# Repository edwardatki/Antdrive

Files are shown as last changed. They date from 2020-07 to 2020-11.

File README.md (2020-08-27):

# Antdrive
A lightweight motor driver designed for antweight combat robots. Setup instructions are available [here](https://github.com/edwardatki/Antdrive/blob/master/documentation/guide.pdf).

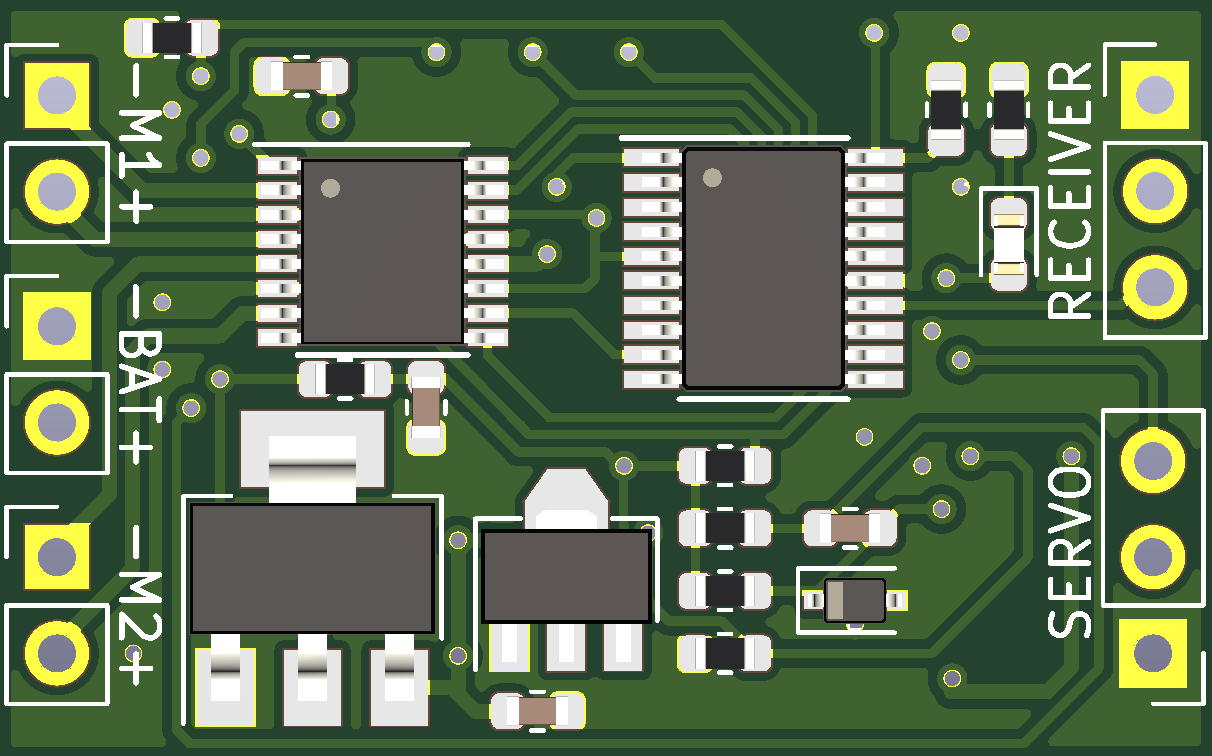
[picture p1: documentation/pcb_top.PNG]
PCB Top

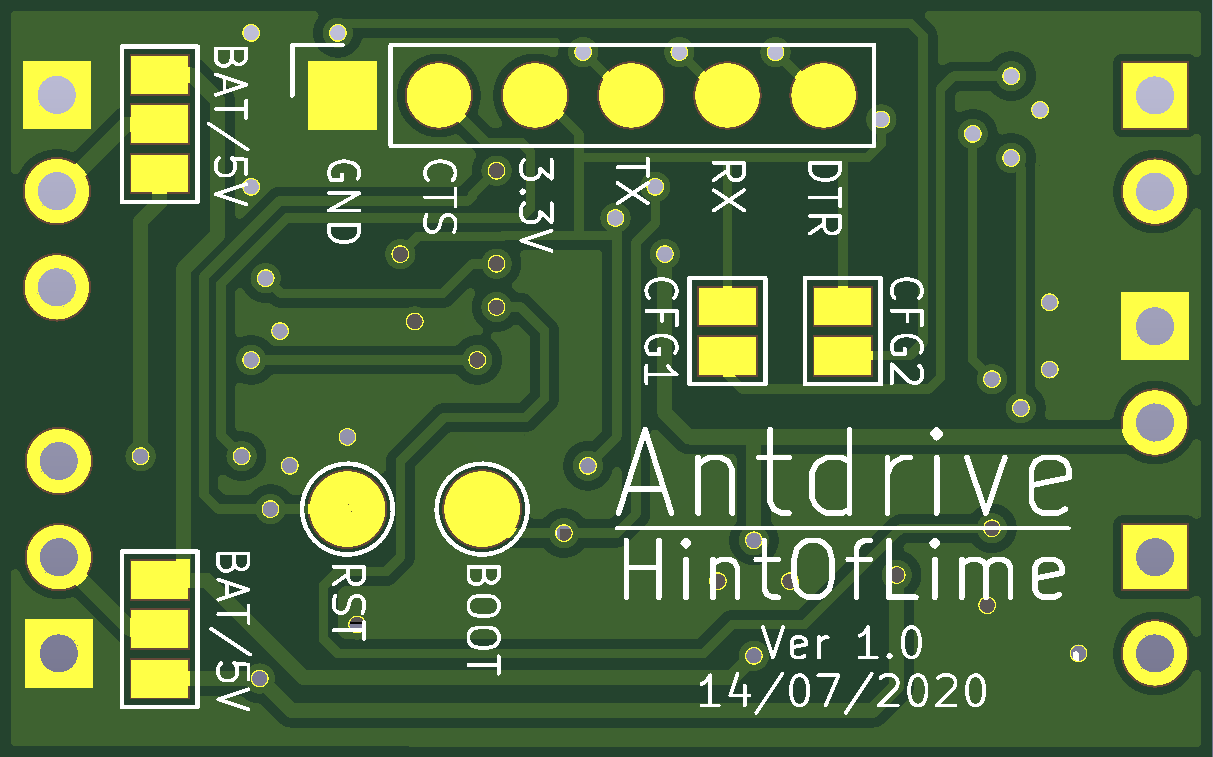
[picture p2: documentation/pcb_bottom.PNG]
PCB Bottom


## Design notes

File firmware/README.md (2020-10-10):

# Programming guide
#### Required software
You will need to have the following software installed
* [Arduino IDE](https://www.arduino.cc/en/Main/software)
* [STM32CubeProgrammer](https://www.st.com/en/development-tools/stm32cubeprog.html)

#### Install STM32 cores
1. In the Arduino IDE goto 'File' and then 'Preferences'
2. Add the following link to the 'Additional Boards Manager URLs' field:
https://github.com/stm32duino/BoardManagerFiles/raw/master/STM32/package_stm_index.json
3. Click 'Ok' to close the menu
4. Goto 'Tools', then 'Boards' and then click on 'Boards Manager'
5. Select 'STM32' Cores and click 'Install'
6. STM32 boards should now show up in the board selection menu

#### Board settings
In the tools menu make sure your board settings match this image
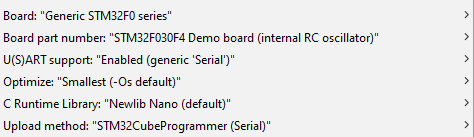
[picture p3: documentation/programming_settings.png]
Board settings


#### Programming
1. Connect and FTDI and select the appropriate COM port
2. Press the FTDI to the corresponding set of pads on the board
3. Press upload
4. Keep pressing the FTDI to the board until the upload it complete

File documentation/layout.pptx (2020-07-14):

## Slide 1

Status LED

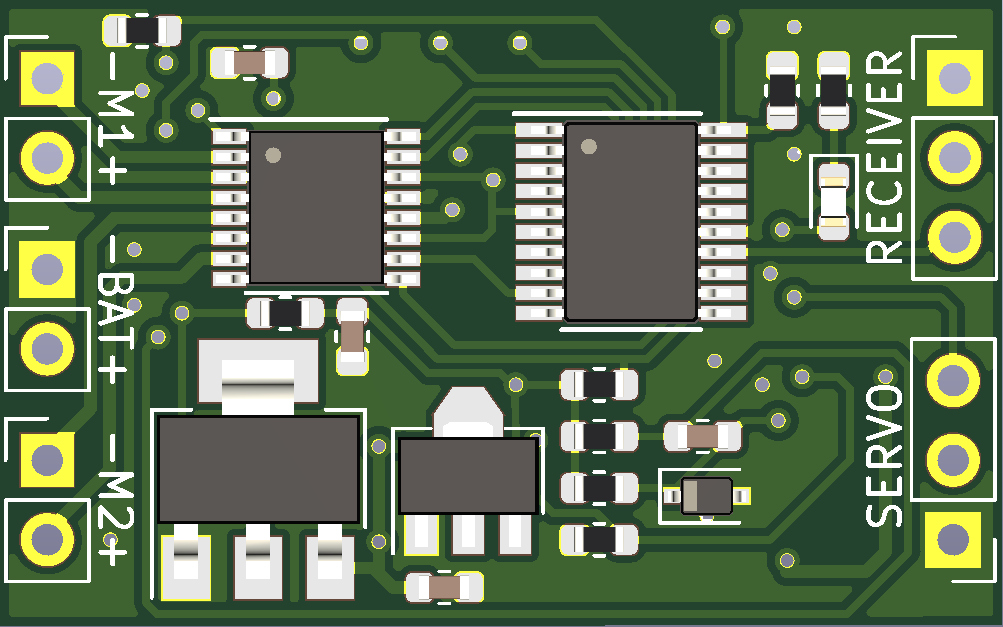
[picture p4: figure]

Motor 1

Receiver

Battery

Motor 2

Servo or ESC

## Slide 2

Programming pads

Configuration jumpers

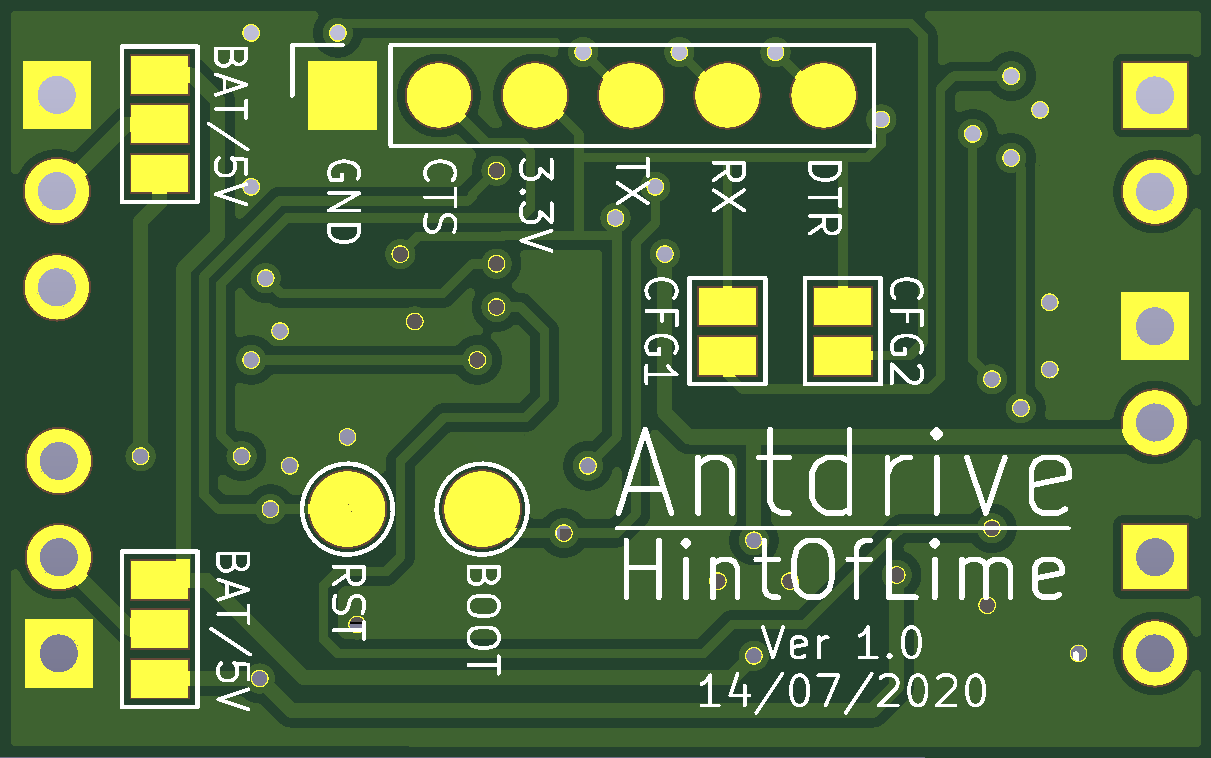
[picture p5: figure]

Voltage selection jumpers

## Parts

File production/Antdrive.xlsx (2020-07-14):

Comment | Designator | Footprint | LCSC Part
AMS117-5.0 | U1 | SOT-223-3 | C6187
STM32F030F4P6TR | U2 | TSSOP-20 | C89040
DRV8848PWPR | U3 | TSSOP-16 | C131079
HT7533-1 | U5 | SOT-89-3 | C14289
1kΩ | R1, R2, R3, R6, R8 | 0603 | C21190
220Ω | R4 | 0603 | C22962
100kΩ | R5 | 0603 | C25803
10kΩ | R7 | 0603 | C25804
10uF | C1, C2, C3 | 0603 | C19702
2.2uF | C4 | 0603 | C23630
KT-0603R | D1 | 0603 | C2286
KDZ3.3V-RTK/P | D2 | SOD-323 | C155470

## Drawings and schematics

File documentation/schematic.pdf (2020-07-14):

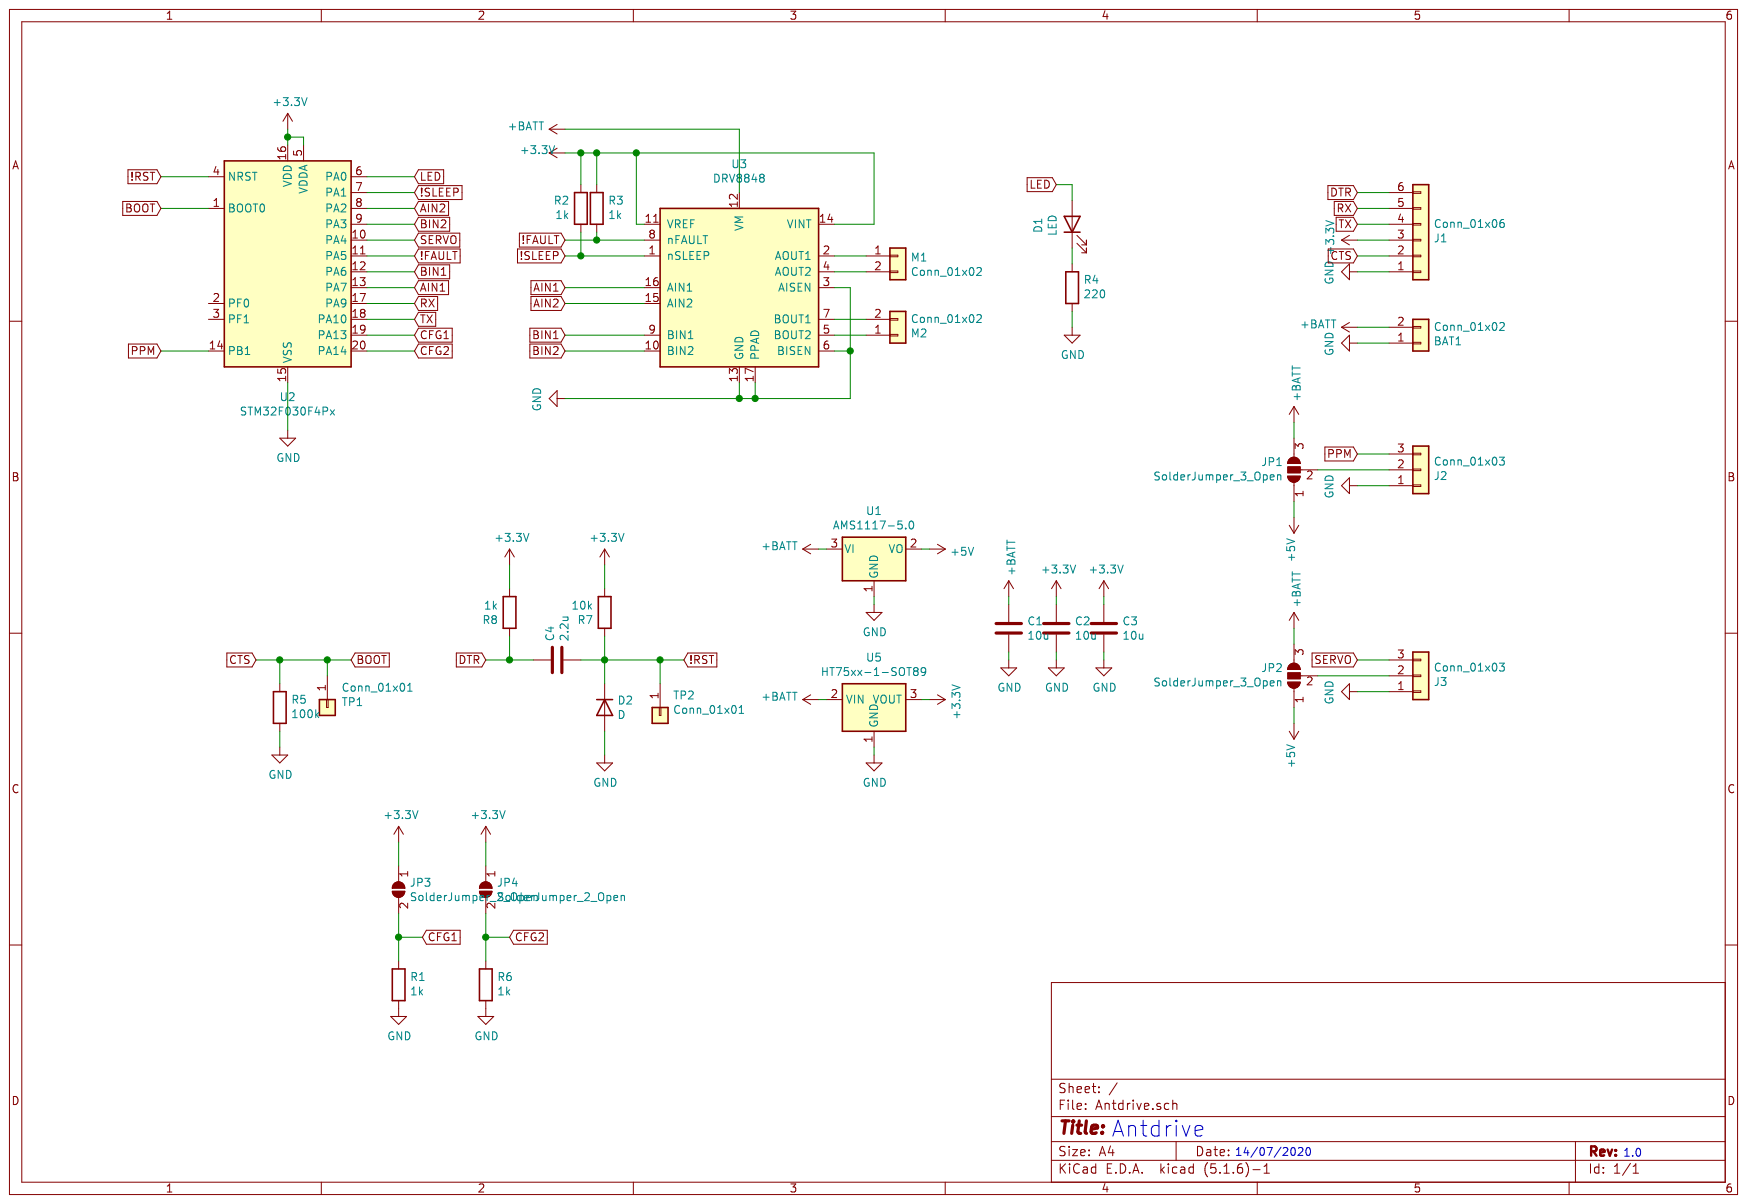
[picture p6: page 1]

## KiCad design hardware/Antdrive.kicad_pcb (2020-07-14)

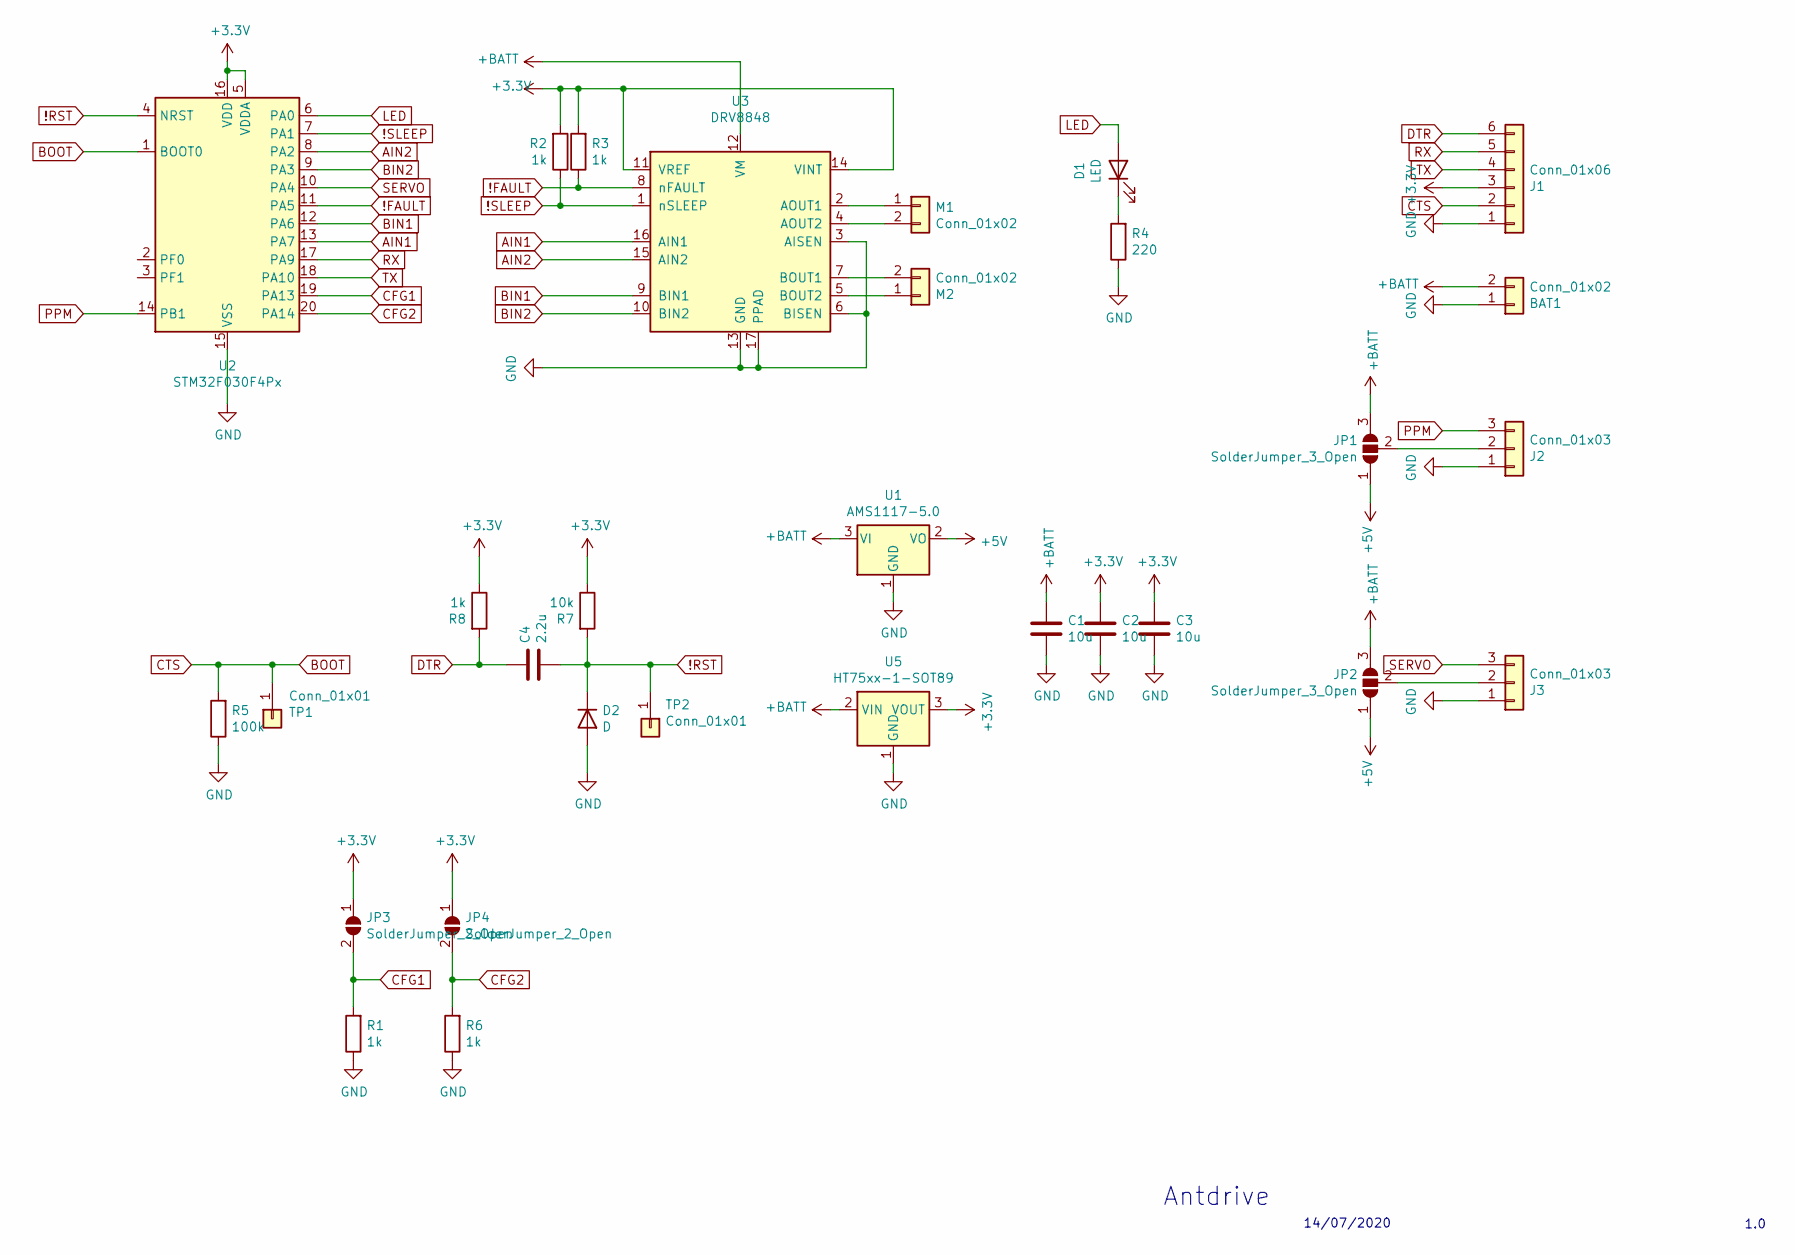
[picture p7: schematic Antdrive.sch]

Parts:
BAT1: Conn_01x02; PinHeader_1x02_P2.54mm_Vertical
C1, C2, C3: 10u; C_0603_1608Metric
C4: 2.2u; C_0603_1608Metric
D1: LED; LED_0603_1608Metric
D2: D; D_SOD-323
J1: Conn_01x06; PinSocket_1x06_P2.54mm_Vertical
J2, J3: Conn_01x03; PinHeader_1x03_P2.54mm_Vertical
JP1, JP2: SolderJumper_3_Open; SolderJumper-3_P1.3mm_Open_Pad1.0x1.5mm_NumberLabels
JP3, JP4: SolderJumper_2_Open; SolderJumper-2_P1.3mm_Open_Pad1.0x1.5mm
M1, M2: Conn_01x02; PinHeader_1x02_P2.54mm_Vertical
R1, R2, R3, R6, R8: 1k; R_0603_1608Metric
R4: 220; R_0603_1608Metric
R5: 100k; R_0603_1608Metric
R7: 10k; R_0603_1608Metric
TP1, TP2: Conn_01x01; TestPoint_Pad_D2.0mm
U1: AMS1117-5.0; SOT-223-3_TabPin2
U2: STM32F030F4Px; TSSOP-20_4.4x6.5mm_P0.65mm
U3: DRV8848; TSSOP-16-1EP_4.4x5mm_P0.65mm
U5: HT75xx-1-SOT89; SOT-89-3

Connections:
!FAULT: R3.1, U2.11 (PA5), U3.8 (nFAULT)
!RST: C4.2, D2.1 (K), R7.2, TP2.1, U2.4 (NRST)
!SLEEP: R2.1, U2.7 (PA1), U3.1 (nSLEEP)
+3V3: C2.1, C3.1, J1.3, JP3.1 (A), JP4.1 (A), R2.2, R3.2, R7.1, R8.1, U2.5 (VDDA), U2.16 (VDD), U3.11 (VREF), U3.14 (VINT), U5.3 (VOUT)
+5V: JP1.1 (A), JP2.1 (A), U1.2 (VO)
+BATT: BAT1.2, C1.1, JP1.3 (B), JP2.3 (B), U1.3 (VI), U3.12 (VM), U5.2 (VIN)
AIN1: U2.13 (PA7), U3.16 (AIN1)
AIN2: U2.8 (PA2), U3.15 (AIN2)
BIN1: U2.12 (PA6), U3.9 (BIN1)
BIN2: U2.9 (PA3), U3.10 (BIN2)
BOOT: J1.2, R5.2, TP1.1, U2.1 (BOOT0)
CFG1: JP3.2 (B), R1.2, U2.19 (PA13)
CFG2: JP4.2 (B), R6.2, U2.20 (PA14)
DTR: C4.1, J1.6, R8.2
GND: BAT1.1, C1.2, C2.2, C3.2, D2.2 (A), J1.1, J2.1, J3.1, R1.1, R4.1, R5.1, R6.1, U1.1 (GND), U2.15 (VSS), U3.3 (AISEN), U3.6 (BISEN), U3.13 (GND), U3.17 (PPAD), U5.1 (GND)
LED: D1.2 (A), U2.6 (PA0)
unnamed: D1.1 (K), R4.2
unnamed: J2.2, JP1.2 (C)
unnamed: J3.2, JP2.2 (C)
unnamed: M1.1, U3.2 (AOUT1)
unnamed: M1.2, U3.4 (AOUT2)
unnamed: M2.1, U3.5 (BOUT2)
unnamed: M2.2, U3.7 (BOUT1)
PPM: J2.3, U2.14 (PB1)
RX: J1.5, U2.17 (PA9)
SERVO: J3.3, U2.10 (PA4)
TX: J1.4, U2.18 (PA10)

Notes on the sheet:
14/07/2020
Antdrive
1.0

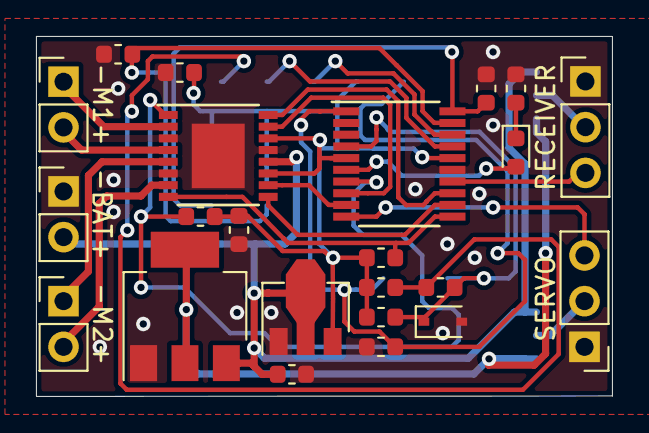
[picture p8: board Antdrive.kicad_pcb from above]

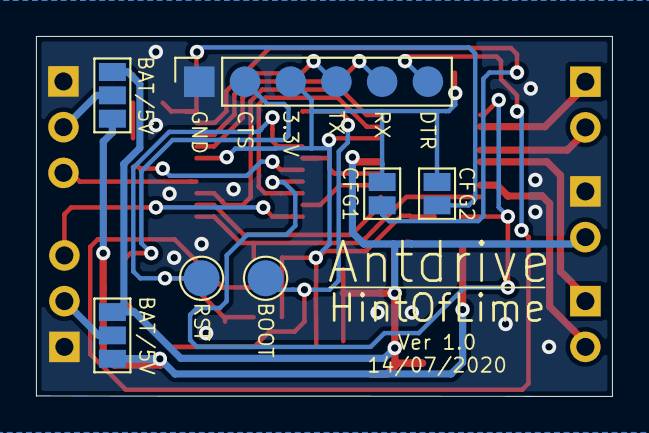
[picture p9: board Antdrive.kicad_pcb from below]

Board: 2 copper layers, 32.0 x 20.0 mm, 30 parts (7 on the bottom side), 27 nets.

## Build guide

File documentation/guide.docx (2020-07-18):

Antdrive V1.0

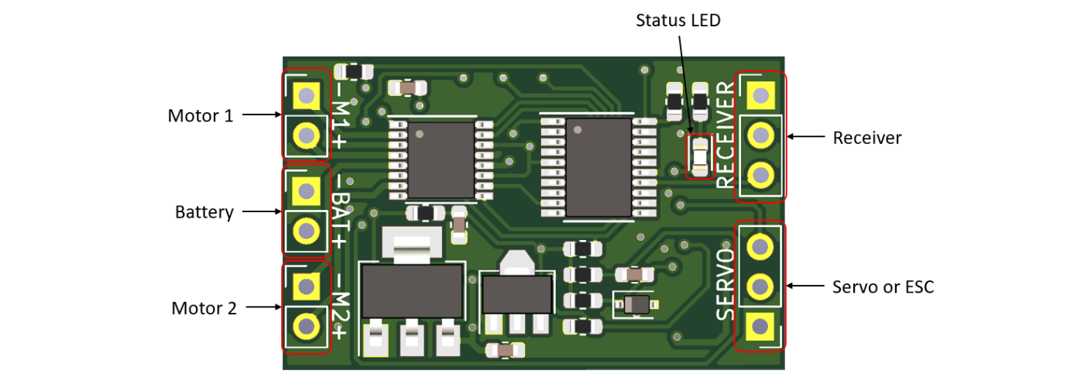
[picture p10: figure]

GND

VCC

SIGNAL

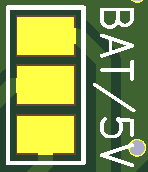
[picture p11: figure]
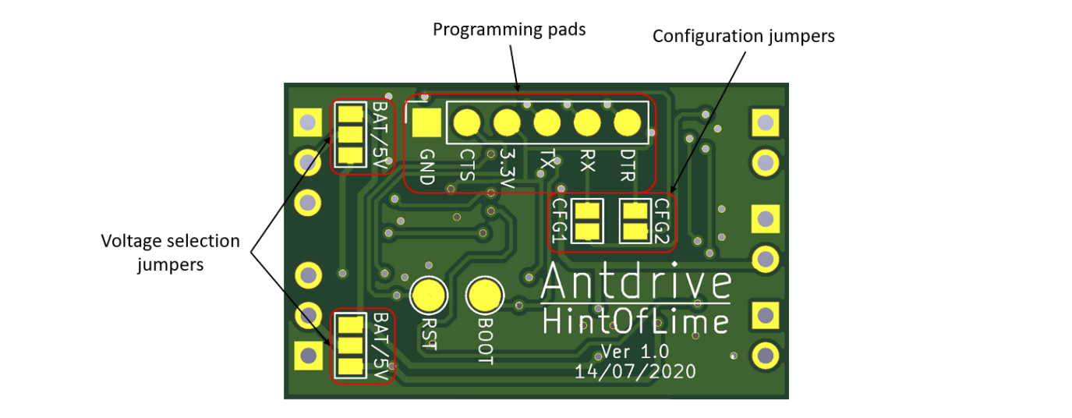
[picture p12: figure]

CFG1 selects the board’s input mode. By default the board will use PPM mode, if jumpered it will use PWM mode.

CFG2 controls whether to mix the input channels. By default mixing is not enabled, if jumpered the channels will be mixed.

Both receiver and servo ports have voltage selection jumpers. These jumpers select whether to output battery voltage or regulated 5V on each port. If in doubt set these to 5V.

In PPM mode the board will take the PPM signal from the receiver port and use channels 1 and 2 to control the motors. Channel 3 will be output as PWM on the servo port to control either a servo or an ESC.

In PWM mode the board the board will take PWM signals from both the receiver and servo ports to control the motors.

The Status LED will blink twice on power up. When receiving a valid control signal the LED will be solid on. If a fault is detected the LED will flash rapidly.

Battery voltage selected

5V selected

Ensure positive and negative battery wires are the correct way around before connecting to the board for the first time, there is no reverse polarity protection built in.

Source files available here:

https://github.com/edwardatki/Antdrive

Input voltage: 6.5V to 15V

Motor current: 2A per channel

BEC current: 1A

Dimensions: 32x20x3mm

Weight: 1.8g

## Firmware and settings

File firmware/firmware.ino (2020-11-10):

#include <Servo.h>

// Pin definintions
#define MOT_1A_PIN PA7
#define MOT_1B_PIN PA2
#define MOT_2A_PIN PA6
#define MOT_2B_PIN PA3
#define MOT_SLEEP_PIN PA1
#define MOT_FAULT_PIN PA5
#define LED_PIN PA0
#define SERVO_PIN PA4
#define PPM_PIN PB1
#define CFG1_PIN PA13
#define CFG2_PIN PA14

// Deadzone for drive motors
#define DEADZONE 10

// Config options
static bool INPUT_MODE;
static bool MIXING;

// Servo object for outputting throttle channel
Servo weapon;

// PPM decoding configuration
#define PPM_MIN_SYNC 5000
#define PPM_MIN_PULSE 600
#define PPM_MAX_PULSE 1600

// PWM decoding configuration
#define PWM_MIN_PULSE 1000
#define PWM_MAX_PULSE 2000

#define CHANNELS 8
static int channels[CHANNELS];

static int lastUpdate;
static bool haveUpdate;

void ppmInterrupt () {
  static char counter = 0;
  static unsigned long startMicros = 0;

  bool val = digitalRead(PPM_PIN);
  
  if (val) {
    startMicros = micros();
  } else {
    int duration = micros() - startMicros;
    if (duration > PPM_MIN_SYNC) {
      counter = 0;
    } else {
      duration =  constrain(duration, PPM_MIN_PULSE, PPM_MAX_PULSE);
      channels[counter] = map(duration, PPM_MIN_PULSE, PPM_MAX_PULSE, -255, 255);
      counter += 1;
    }

    lastUpdate = millis();
    haveUpdate = true;
  }
}

void pwmInterruptA () {
  static unsigned long startMicros = 0;

  bool val = digitalRead(PPM_PIN);
  
  if (val) {
    startMicros = micros();
  } else {
    int duration = constrain(micros() - startMicros, PWM_MIN_PULSE, PPM_MAX_PULSE);
    channels[0] = map(duration, PWM_MIN_PULSE, PWM_MAX_PULSE, -255, 255);

    lastUpdate = millis();
    haveUpdate = true;
  }
}

void pwmInterruptB () {
  static unsigned long startMicros = 0;
  
  bool val = digitalRead(SERVO_PIN);
  
  if (val) {
    startMicros = micros();
  } else {
    int duration = constrain(micros() - startMicros, PWM_MIN_PULSE, PPM_MAX_PULSE);
    channels[1] = map(duration, PWM_MIN_PULSE, PWM_MAX_PULSE, -255, 255);

    lastUpdate = millis();
    haveUpdate = true;
  }
}

// Set motor 0 or 1 to a speed between -255 and 255
void setMotor (bool motor, int value) {
  if (motor == 0) {
    if (value > 0+DEADZONE) {
      analogWrite(MOT_1A_PIN, abs(value));
      digitalWrite(MOT_1B_PIN, LOW);
    } else if (value < 0-DEADZONE) {
      analogWrite(MOT_1A_PIN, 255-abs(value));
      digitalWrite(MOT_1B_PIN, HIGH);
    } else {
      analogWrite(MOT_1A_PIN, 255);
      digitalWrite(MOT_1B_PIN, HIGH);
    }
  } else {
    if (value > 0+DEADZONE) {
      analogWrite(MOT_2A_PIN, abs(value));
      digitalWrite(MOT_2B_PIN, LOW);
    } else if (value < 0-DEADZONE) {
      analogWrite(MOT_2A_PIN, 255-abs(value));
      digitalWrite(MOT_2B_PIN, HIGH);
    } else {
      analogWrite(MOT_2A_PIN, 255);
      digitalWrite(MOT_2B_PIN, HIGH);
    }
  }
}

void setup() {
  // Set pin modes (don't set PWM pins to OUTPUT on STM32)
  //pinMode(MOT_1A_PIN, OUTPUT);
  pinMode(MOT_1B_PIN, OUTPUT);
  //pinMode(MOT_2A_PIN, OUTPUT);
  pinMode(MOT_2B_PIN, OUTPUT);
  pinMode(MOT_SLEEP_PIN, OUTPUT);
  pinMode(MOT_FAULT_PIN, INPUT);
  pinMode(LED_PIN, OUTPUT);
  //pinMode(SERVO_PIN, OUTPUT);
  pinMode(PPM_PIN, INPUT_PULLUP);
  pinMode(CFG1_PIN, INPUT);
  pinMode(CFG2_PIN, INPUT);

  // Set motors to idle and disable motor driver
  setMotor(0, 0);
  setMotor(1, 0);
  digitalWrite(MOT_SLEEP_PIN, LOW);

  // Set configuration varialbles from config jumpers
  INPUT_MODE = digitalRead(CFG1_PIN);
  MIXING = digitalRead(CFG2_PIN);

  // Flash LED to indicate ready
  digitalWrite(LED_PIN, HIGH);
  delay(50);
  digitalWrite(LED_PIN, LOW);
  delay(100);
  digitalWrite(LED_PIN, HIGH);
  delay(50);
  digitalWrite(LED_PIN, LOW);
  delay(100);

  if (INPUT_MODE) {
    pinMode(SERVO_PIN, INPUT_PULLUP);
    attachInterrupt(PPM_PIN, pwmInterruptA, CHANGE);
    attachInterrupt(SERVO_PIN, pwmInterruptB, CHANGE);
  } else {
    attachInterrupt(PPM_PIN, ppmInterrupt, CHANGE);
  }
}

void loop() {
  // Fault check disabled because it's always comes back positive
  // Driver still operates so the problem is between driver and microcontrollerU
  /*
  // Check for motor driver fault
  if (!digitalRead(MOT_FAULT_PIN)) {
    // If fault detected flash led and exit loop
    digitalWrite(LED_PIN, HIGH);
    delay(50);
    digitalWrite(LED_PIN, LOW);
    delay(50);
    return;
  }
  */

  static bool signalReady = false;
  if (!signalReady) {
    static unsigned int readyCycles = 0;
    if (haveUpdate) readyCycles += 1;
    if (readyCycles > 500) {
      if (!INPUT) {
        // Attach weapon to pin and set to idle
        weapon.attach(SERVO_PIN, 1000, 2000);
        weapon.write(0);
      }

      signalReady = true;
    }
  } else {
    // Check if no signal for a while
    if (abs((int)millis() - lastUpdate) > 200) {
      // No signal so go to failsafe
      
      // Disable LED to indicate receiver disconnected
      digitalWrite(LED_PIN, LOW);
    
      // Disable motor driver
      digitalWrite(MOT_SLEEP_PIN, LOW);
    
      // Set motors to idle
      setMotor(0, 0);
      setMotor(1, 0);
  
      if (!INPUT_MODE) {
        // Set weapon to ilde
        weapon.write(0);
      }
    } else if (haveUpdate) {
      // Still got signal so update motor and weapon outputs
      
      // Enable LED to indicate receiver connected
      digitalWrite(LED_PIN, HIGH);
    
      // Enable motor driver
      digitalWrite(MOT_SLEEP_PIN, HIGH);
    
      // Check if channel mixing is enabled
      if (MIXING) {
        // Mix channels
        int mot1 = min(max(channels[1]-channels[0], -255), 255);
        int mot2 = min(max(channels[1]+channels[0], -255), 255);
        // Set motor speeds
        setMotor(0, mot1);
        setMotor(1, mot2);
      } else {
        // Set motor speeds
        setMotor(0, channels[0]);
        setMotor(1, channels[1]);
      }
  
      if (!INPUT_MODE) {
        // PWM mode
        // Write throttle channel to servo pin for weapon
        weapon.write(map(channels[2], -255, 255, 0, 180));
      }

      haveUpdate = false;
    }
  }
}

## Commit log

2020-05-16 Fix auto reset circuits
    [Antdrive.kicad_pcb, Antdrive.sch]
2020-05-29 Update schematic
    [Antdrive.sch]
2020-05-29 PCB updated
    [Antdrive.kicad_pcb, Antdrive.sch]
2020-05-29 Update production files
    [Antdrive.kicad_pcb, Antdrive.sch, Antdrive.xlsx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]
2020-05-30 Fix production file errors
    [Antdrive-top-pos.xlsx]
2020-06-14 Initial firmware
    [Antdrive.sch]
2020-06-15 Ver 0.3
    Added config jumpers and hopefully fixed programming circuitry
    [Antdrive.kicad_pcb, Antdrive.sch]
2020-07-14 Added documentation
    [Antdrive.kicad_pcb, Antdrive.sch, Antdrive.xlsx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]
2020-07-14 Reorganize files
    [Antdrive.kicad_pcb, Antdrive.sch]
2020-07-14 Add PWM control mode
2020-11-10 Move receiver signal processing into interrupts and enable motor braking
